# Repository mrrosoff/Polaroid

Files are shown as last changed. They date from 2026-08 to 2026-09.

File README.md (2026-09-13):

# Polaroid

A battery-powered digital Polaroid. A 4" six-color e-ink panel that lives on a fridge, cycles
through photos, and syncs new ones when you shake it. Runs about a month per charge. Built as a
wedding gift.

## How it works

The server pre-renders every photo into a raw framebuffer matching the panel's resolution and
palette exactly, so the device never decodes, dithers or resizes. It wakes, streams a file from
flash to the panel, and sleeps.

```
 photo.jpg ──▶ [ backend ]                      [ device ]
                 crop 400×600 full-bleed          wake (timer or shake)
                 Polaroid film curve              read index from RTC memory
                 Floyd-Steinberg → 6 inks         stream .bin from LittleFS → SPI
                 pack 4bpp → 120,000 B            deep sleep
                 store .bin + preview.png
```

The device always pulls, and the server never reaches back. That is what lets it sleep behind a NAT
on someone else's WiFi for months.

Every wake renders, and some also sync. A shake, a cold boot, or the daily interval coming due will
each do it. The manifest is newest-first, so index 0 is the newest photo. A shake, a cold boot, and
a sync that deleted photos all jump to index 0, and every other wake advances by one and wraps.

Two screens are not photos. Below 5% the panel stops refreshing and shows **CHARGE ME**, clearing
once above 25%, and the gap stops a cell on the threshold swapping every hour. An empty library
shows **ADD PHOTOS**, so a device that has never synced doesn't look broken. The battery card wins
when both apply.

Failure means "keep showing what's already there". A sync that fails falls through to a normal
render, so the panel never goes blank because the network was unhappy.

## Build and flash

```bash
pio run -t upload    # the shipping firmware
pio test -e native   # 39 tests, no hardware needed
```

There is one firmware environment. `logf()` writes to USB serial when a host is attached and
returns immediately when one is not, so bench and battery runs are the same binary.

Deep sleep drops USB, so a sleeping board can only be reflashed by holding BOOT through a reset, or
by catching the few seconds it is awake.

Copy `include/Secrets.h.example` to `Secrets.h` (gitignored) for the device credential and
WiFi networks. The strongest listed network in range wins, so both homes can be listed.

## Hardware

A **Seeed XIAO ESP32S3**, chosen because it charges the cell over the same USB-C you flash through,
has no always-on power LED, and is designed for a 14 µA deep sleep. Its 8 MB costs 50 photos
against a 16 MB board's 123, which is the trade.

The panel is a **Waveshare 4" E Ink Spectra 6 (E6)** with its HAT+ driver board, `EPD_4in0e`.
Native 400 × 600 portrait, 4 bpp, two pixels per byte, which works out to a fixed 120,000 bytes
per frame. Six inks, no grays and no blends. A full refresh takes 15–35 s, measured around 21 s on
this build.

| | black | white | yellow | red | blue | green |
| --- | --- | --- | --- | --- | --- | --- |
| nibble | `0x0` | `0x1` | `0x2` | `0x3` | `0x5` | `0x6` |

Also inside are an Adafruit #2011 2000 mAh cell and an Adafruit #2809 LIS3DH breakout. Orient the
LIS3DH so its X axis lies in the plane of the fridge door, because that is the axis the `Config.h`
thresholds are tuned against. The case is 71.6 × 118.8 × 22.7 mm, its footprint set by the driver
board.

### Wiring

The XIAO breaks out exactly eleven GPIO and this design needs exactly eleven. Every wake source
must be on GPIO0–21 (the RTC domain) and the battery divider must be on ADC1 (the ADC that still
answers while WiFi is up). `D6`/`D7` are GPIO43/44, outside both, so they take the two signals
needing neither.

| Panel | XIAO | GPIO | | LIS3DH | XIAO | GPIO |
| --- | --- | --- | --- | --- | --- | --- |
| `SCK` | D6 | 43 | | `SCL` | D3 | 4 |
| `MOSI` | D7 | 44 | | `SDA` | D2 | 3 |
| `CS` | D10 | 9 | | `INT1` | D1 | 2 |
| `DC` | D9 | 8 | | `3Vo` | 3V3 | |
| `RST` | D8 | 7 | | `GND` | GND | |
| `BUSY` | D5 | 6 | | | | |
| `PWR` | D4 | 5 | | | | |

The cell goes to `B+`/`B-` on the XIAO's underside, sensed through a 2 × 1 MΩ divider into `D0`
(GPIO1, ADC1_CH0). Tests assert no pin is used twice, that `INT1` is RTC-capable, and that battery
sense is on ADC1, so a mistake here fails on your laptop.

Two things will cost you the battery if you skip them. **Gate the panel through `D4`**, because the
E6 driver board's regulator idles in the hundreds of µA even after the panel sleeps, roughly halving
runtime. **Power the LIS3DH at `3Vo`**, bypassing the breakout's LDO and its 29 µA quiescent draw.

## Power

Measured at about 2.2 mA, which is roughly a month per charge.

Nothing the firmware *does* moves that number. Twenty-four refreshes a day, the syncs and the
filesystem together change the discharge rate by less than the measurement noise, so lengthening
`REFRESH_INTERVAL_SECONDS` buys nothing. What the firmware *leaves behind* was most of the drain.
The panel board stays powered while we sleep and pulls its inputs up to its own VCC, so holding the
six data and control lines at 0 V sank current through those pull-ups continuously. Leaving them
high-impedance instead cut about 1.9 mA.

The ~2 mA that remains is the driver board's own quiescent draw on a rail that never turns off.
Getting past it means hardware, namely a high-side P-MOSFET on its VCC rather than a GPIO, since the
board pulls ~45 mA during a refresh.

**Measure it with the on-flash log, never over USB.** The ADC divider sits on the battery terminal,
so a board on a charger reads the charger. Every wake appends `boot,rtc_ms,mv,wake,host` to
`/vlog.csv`. Plug in and shake to dump it, or send `c` to clear. Fit a slope through the `host=0`
rows ordered by `rtc_ms`, and compare slopes only within the same voltage window, since a LiPo's mV
per mAh changes across the curve.

## Protocol

Base URL `https://api.maxrosoff.com/polaroid`. Device requests carry a bearer token of the form
`<deviceId>.<secret>`, both in `Secrets.h`. The API stores only the secret's SHA-256 alongside the
id in the `website-devices` table. It is a static secret rather than a JWT because the device has no
clock worth trusting an `exp` against.

`GET /photos` returns `{ id, hash, uploadedAt, previewUrl }`, newest first and uncapped. The device
keeps the newest `MAX_PHOTOS` in that order and diffs against its local manifest for fetch, delete
and keep sets. Only fetch costs bandwidth.

`POST /photo` with `{ "id": ... }` returns exactly 120,000 bytes. It **must** send
`Accept: application/octet-stream`, or API Gateway returns 160,000 base64 characters instead. It
honours the Lambda's `isBase64Encoded` only when Accept matches the API's `binaryMediaTypes`.
Success is the file being exactly 120,000 bytes once closed, so a truncated body, a 404 and a
dropped connection all land as a short file and retry next sync.

`POST /upload` and `POST /remove` sit behind the site's passkey auth, and the device never calls
them.

There is no database for photos. The list is a `ListObjectsV2` whose Key, ETag and LastModified are
exactly the id, hash and timestamp a table would hold.

## Where the code lives

This repo is the device. The service lives in
[Personal-Website](https://github.com/mrrosoff/Personal-Website), which holds the image pipeline
and four Lambda handlers under `api/endpoints/polaroid/`, plus the upload page at
`maxrosoff.com/polaroid`.

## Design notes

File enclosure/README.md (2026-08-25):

# Enclosure

Two printed parts — front bezel and rear tray — held together by four M2 self-tapping screws that
enter horizontally through the tray's side walls into flanges on the bezel.

**71.6 × 118.8 × 22.7 mm.**

```bash
./render.sh          # regenerates every STL and preview from the .scad
```

The checked-in `stl/` and `preview/` files are outputs. Run `render.sh` after any change.

## Before you print

**Measure `board_t`.** 7.0 mm, calipered on the real board with the Pi headers removed. It sets the
total thickness directly, and the vendor doesn't give it.

**Check which edge the FPC leaves on.** `fpc_fold_gap` puts a 2.5 mm gap at the case's bottom edge
for the ribbon to fold into. On the wrong edge, assembly crushes it.

**Print the bezel in a dark colour.** E-ink white is bone, around 78% reflectance. A white bezel
around it reads as one big dingy slab and the Polaroid shape drawn on the panel disappears. Dark
grey, black, or a wood-fill makes the white pop.

## Notes

**Screws, not clips.** This is the one enclosure here that gets deliberately shaken.

**Screws live in the top and bottom rims, not the side margins.** That's what let the flanges get
longer *and* the side bezels get thinner — otherwise those trade directly against each other, since
a flange in the side margin forces that margin to be `flange_inset + flange_w + clearance` wide.
Side bezel is 1.5 mm of plastic beside the board — the wall, and nothing else — and 8.1 mm beside
the visible image. The rims are 7.35 mm, which is the screw head clearing the corner radius plus the
boss behind it, and nothing more. The boss is 4.5 mm around a 2.0 mm pilot, so its wall is 1.25 mm —
thin, deliberately, because the boss diameter is the rim's entire cost. If a flange splits on first
assembly, `side_boss_od` is the number that did it.

**One magnet, dead centre.** Anywhere else and the case rotates until its centre of mass hangs under
the magnet. The pocket recesses it flush so the case sits flat instead of pivoting on a bump.
The pocket swallows it with 0.8 mm to spare, so the hold comes through a thin skin rather than the
magnet's own face — a magnet standing even 0.2 mm proud is what the case then rocks on. Its ceiling
is a 29 mm circular bridge; if your printer sags there, pause at that layer and drop the magnet in —
it's adhesive-backed.

**The floor is 1.5 mm, and the magnet sits in a boss.** The floor used to be 5.6 mm everywhere so
that a 3 mm disc in the middle intruded on nothing — 4 mm of case thickness bought for one circle.
Now the floor is the wall thickness and the 5 mm the magnet needs is paid for over a 34 mm boss
standing proud on the inside. The cost is that the floor is no longer flat, so the component
placements are hoisted to the top level and asserted clear of the boss.

**There is no chin.** There was 10 mm of one, on the theory that the parts had run out of floor under
a board that spans the entire pocket. Laid out against the real footprints they had not — battery
along the top wall, MCU and accelerometer along the bottom, 30 mm of nothing between them. The
placement assertions are the claim that this is true, and they pass at `chin = 0`.

**The assertions are load-bearing.** They check that the screw flanges exist where the screws
arrive, that the head's counterbore lands on flat wall rather than the corner radius, that neither
reaches the display board, and that no component on the tray floor lands on the magnet boss. One caught a 2.5 mm overhang while this file was being written;
that class of error is invisible until something is printed and assembled.

**`render.sh` also intersects the two parts.** The assertions compare numbers to numbers and
structurally cannot see two solids sharing space. That is what let the bezel's square flange corners
sit 0.67 mm inside the tray's rounded interior corners, down all 12 mm of flange — which held the
bezel proud at four points and bowed its long sides when the screws pulled the ends down. The
intersection must come out empty; `fit_check.scad` is the model, and the build fails on anything
else.

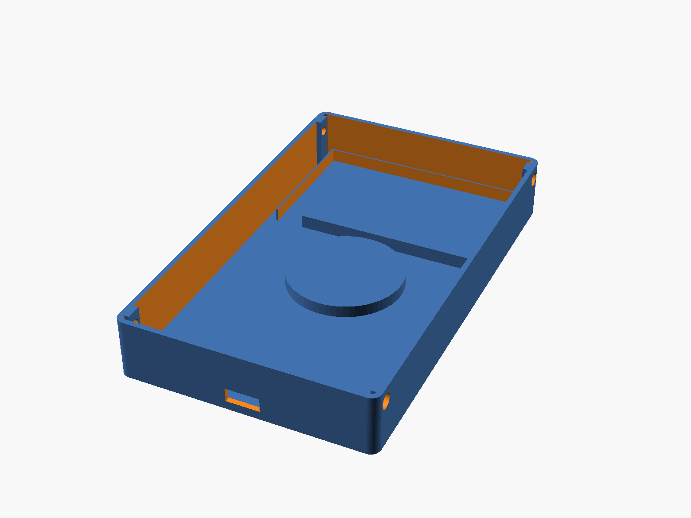
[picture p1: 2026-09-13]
enclosure/preview/03_tray_interior.png

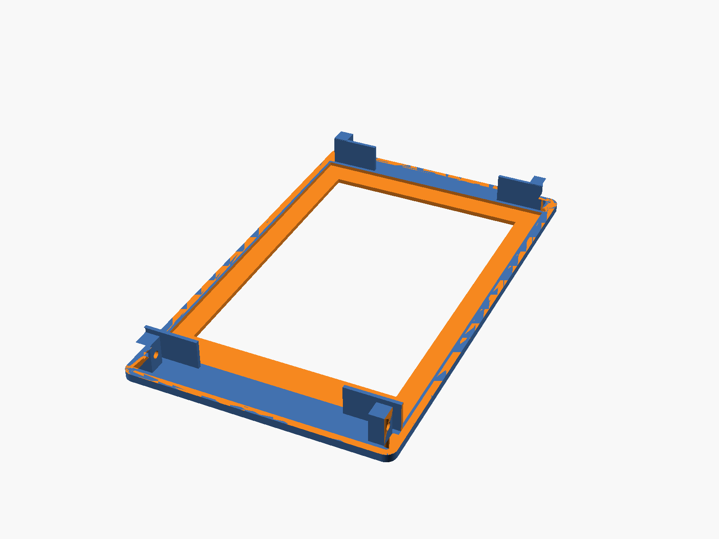
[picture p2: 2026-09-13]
enclosure/preview/02_bezel_iso.png

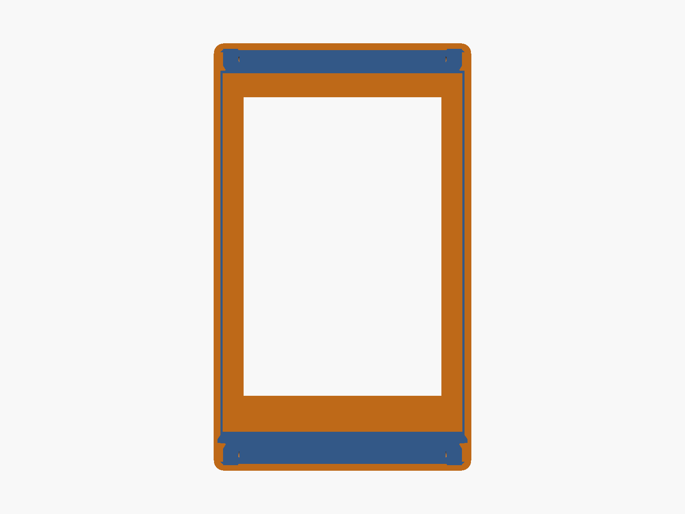
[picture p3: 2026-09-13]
enclosure/preview/01_bezel_front.png

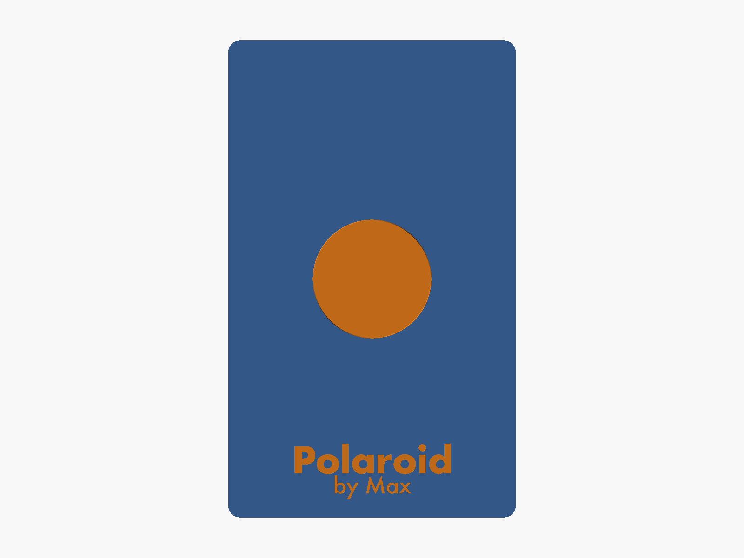
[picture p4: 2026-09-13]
enclosure/preview/04_tray_back.png

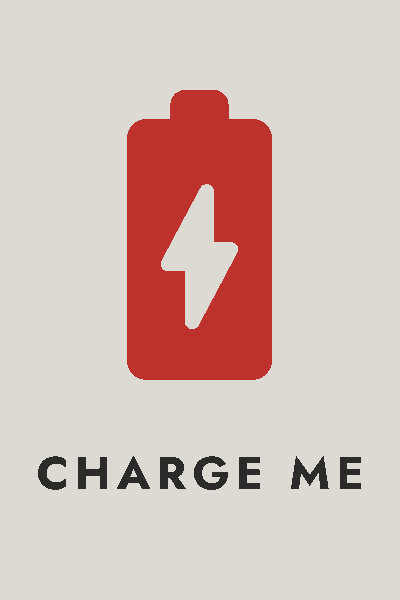
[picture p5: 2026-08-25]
tools/charge_me_preview.png

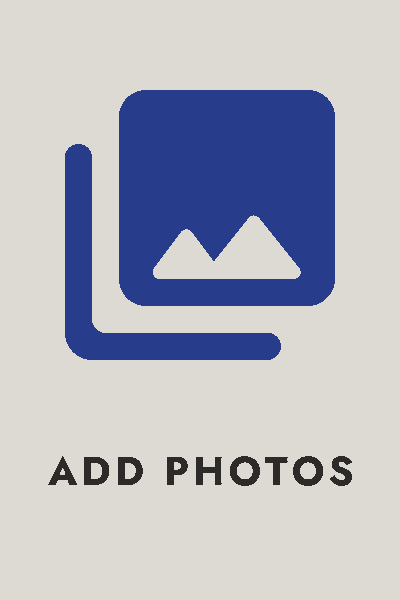
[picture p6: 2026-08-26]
tools/add_photos_preview.png

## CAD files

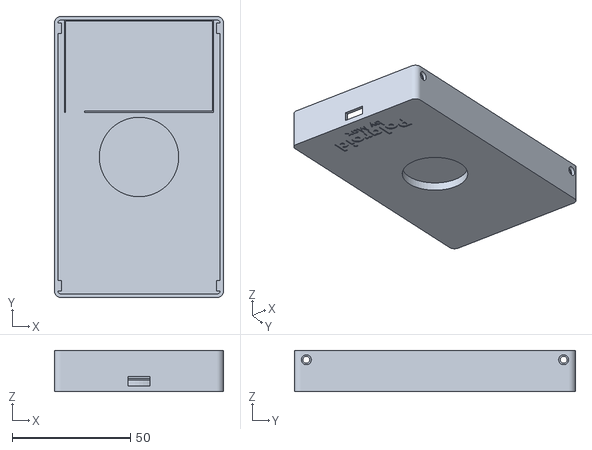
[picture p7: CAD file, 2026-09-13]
enclosure/stl/rear_tray.stl
71.6 x 118.8 x 17.5

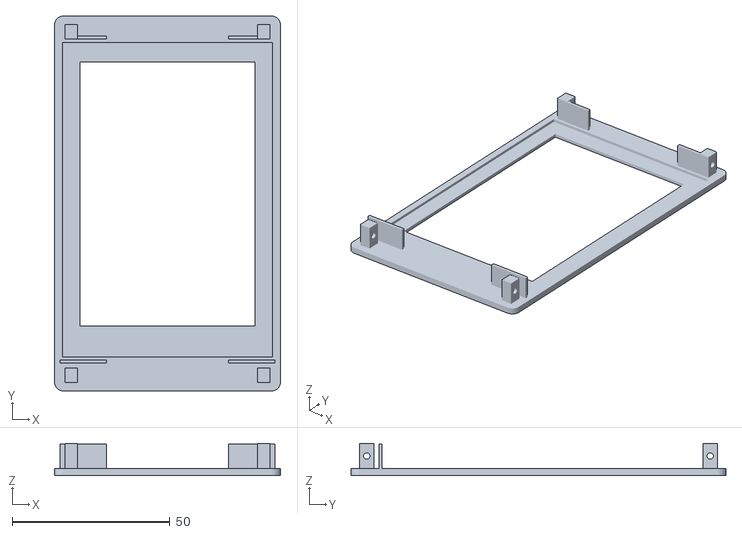
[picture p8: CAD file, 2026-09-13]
enclosure/stl/front_bezel.stl
71.6 x 118.8 x 10.2

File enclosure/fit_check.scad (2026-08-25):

// Interference check: the two parts, assembled, must not share any volume.
// Renders empty when they don't. render.sh fails on anything else.
//
// This is the one class of error the assertions in polaroid_enclosure.scad
// cannot see — they check numbers against each other, not solids against
// solids. It caught square flange corners buried 0.67mm in the tray's rounded
// interior corners, which held the bezel proud and bowed its long sides.
use <polaroid_enclosure.scad>

// The parts are drawn in one XY frame and mate by flipping Z about the plane
// where the bezel's back face meets the tray's rim.
mate_z = total_thickness_mm();

intersection() {
    translate([0, 0, mate_z]) mirror([0, 0, 1]) front_bezel();
    rear_tray();
}

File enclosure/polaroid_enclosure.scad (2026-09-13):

// Polaroid enclosure — 2-part (front bezel + rear tray), screwed together.
//
// The panel is natively 400x600 portrait, so case-X is width and case-Y is
// height, running along the panel's long 101mm edge.
//
// Hardware (vendor spec, waveshare.com/wiki/4inch_e-Paper_HAT+_(E)_Manual):
//   - Driver board (HAT+):  101.0 x 68.0mm      <- sets the case footprint
//   - Raw panel glass:       99.0 x 66.0 x 0.85mm
//   - Active area:           84.6 x 56.40mm
//   - MCU: Seeed XIAO ESP32S3, 21 x 17.5mm
//   - Battery: Adafruit #2011 LiPo, 60 x 36 x 7mm
//   - Accelerometer: Adafruit LIS3DH breakout, 25 x 19mm
//   - Magnet: one 29mm dia x 3mm neodymium disc, adhesive-backed
//
// The photo runs full-bleed across all 400x600 and nothing hides behind the
// bezel: a chin kept for looks would have to cover a quarter of a $45 panel.
//
// PRINT IT IN A DARK COLOUR. E-ink white is bone (~78% reflectance); a white
// bezel reads as one dingy slab and the Polaroid shape vanishes.
//
// Screws rather than clips: this is the one enclosure in the house that gets
// deliberately shaken, and snap-fit works loose.
//
// Render one part at a time:
//   openscad -D part=\"bezel\" -o stl/front_bezel.stl polaroid_enclosure.scad
//   openscad -D part=\"tray\"  -o stl/rear_tray.stl   polaroid_enclosure.scad
part = "both"; // "bezel" | "tray" | "both" (both = preview only, side by side)

$fn = 64;

// ---- General ----
wall      = 1.5;   // perimeter wall thickness
clearance = 0.3;   // general fit clearance around boards
// The corner and the screw head compete for the same end of the case: the head
// must seat on flat wall outboard of the radius, so every 0.1 of radius pushes
// the screw 0.1 further in and costs 0.1 more rim behind it.
corner_r  = 2.8;

// ---- Side-entry screws ----
// SCREWS LIVE IN THE TOP AND BOTTOM RIMS, NOT THE SIDE MARGINS. A flange in a
// side margin forces that margin to flange_inset + flange_w + clearance, so
// every millimetre of thread engagement costs a millimetre of bezel on both
// sides. At a Y above or below the board there is nothing to collide with, so
// the side margin drops to a bare wall and the flange can be as deep as the
// joint needs.
//
// 4.5 around a 2.0mm pilot leaves a 1.25mm wall, the section that split on the
// Forager print. It is back because the boss diameter is the rim's whole cost,
// and because this flange is 12mm deep into a screw pad rather than a stub in
// open air. If a flange splits on first assembly, this is the number that did
// it.
side_boss_od      = 4.5;
side_pilot_d      = 2.0;   // M2 self-tapping into plastic
side_clear_d      = 2.9;   // shaft passes freely through the tray wall
// Flat-top heads sink flush in a counterbore outside the tray. A 1.6mm head
// into a 1.5mm wall leaves nothing to pull against, so the wall is thickened
// locally with a pad on the INSIDE that the bezel's flange butts against.
head_clear_d      = 4.2;   // 3.8mm M2 pan/cheese head plus fit
head_recess_t     = 1.6;   // full head height — the head disappears
screw_pad_t       = 1.5;
flange_w          = 4.0;   // thread engagement depth
// How far the flange reaches into the tray cavity. It has to stop above the
// battery bay's retaining wall, which it overlaps in plan: 12.0 was fine under
// a 19mm cavity and drove the flange straight through the bay at 12.5.
side_flange_depth = 8.0;
// Clear of the screw pad's inner face, not of the wall's.
flange_inset      = wall + screw_pad_t + clearance;   // 3.3

assert(head_recess_t <= wall + screw_pad_t - 1.2,
       "counterbore leaves under 1.2mm of wall — the head will pull through");

// ---- Display assembly ----
// The BOARD, not the glass, sets the footprint: it's 2mm bigger in both axes.
board_w = 68.0;
board_h = 101.0;
// Measured with calipers, headers removed — but see measured_stack_t, which
// says this reads about 5mm high. Re-measure before trusting it.
board_t = 7.0;

glass_w = 66.0;
glass_h = 99.0;
glass_t = 0.85;    // the glass is genuinely this thin. Handle it accordingly.

active_w = 56.40;
active_h = 84.60;

// ASSUMPTION: the active area is centred on the glass and the glass on the
// board. Vendor drawings give no offsets. Shift with active_offset_* rather
// than moving the pocket. Positive Y moves the window up; the value below is
// what the second printed bezel measured short.
active_offset_x = 0;
active_offset_y = 1.7;

// The bezel laps 0.5mm over the active area on every side. Sizing the window
// to exactly active_w/h would expose the glass's inactive margin as a visible
// grey band whenever the panel is showing white paper.
win_overlap = 0.5;
win_w = active_w - 2 * win_overlap;
win_h = active_h - 2 * win_overlap;

// ASSUMPTION: the FPC exits the glass on the case's BOTTOM edge and folds back
// to the board's connector. This is the gap it folds into. Verify which edge
// yours is on before printing — on the wrong edge it crushes the ribbon.
fpc_fold_gap = 2.5;

// ---- MCU: Seeed XIAO ESP32S3 ----
mcu_w = 21.0;
mcu_l = 17.5;
mcu_component_h = 4.0;  // USB-C shell is the tall part

// ---- Battery: Adafruit #2011, 2000mAh ----
batt_w = 60.0;
batt_h = 36.0;
batt_t = 7.0;
batt_puff_clearance = 2.0;  // Same cell as Forager, same allowance: its
                            // 2.0 came off a real print, this was a guess.

// ---- Accelerometer: Adafruit LIS3DH breakout ----
accel_w = 25.0;
accel_l = 19.0;
accel_h = 3.0;

// ---- Magnet ----
// Dead centre is the only sane place for a single disc: anywhere else and the
// case rotates until its centre of mass swings under the magnet. The pocket
// exists so the magnet sits below the back face — standing proud, it is the
// one bump the case rocks on and it never sits flat against the door.
magnet_d = 29.0;
magnet_t = 3.0;
magnet_pocket_d = magnet_d + 0.6;
magnet_pocket_depth = magnet_t + 0.8;
magnet_back_t = 1.2;    // material left behind the magnet. 0.8 was thin
                        // enough to feel like a membrane; this still holds

// The pocket lives in a boss standing proud of the floor on the INSIDE, so its
// depth is paid for over 34mm of circle rather than by thickening the whole
// back — worth 4mm of case. The cost is that the floor is not flat, and the
// component placements below are asserted clear of the boss.
tray_floor_t = wall;   // 1.5
magnet_boss_h = 3.5;
magnet_boss_d = magnet_pocket_d + 4.0;   // 2mm ring around the pocket

assert(tray_floor_t + magnet_boss_h >= magnet_pocket_depth + magnet_back_t,
       "magnet pocket breaks through the boss into the cavity");

// ---- USB-C access ----
usbc_slot_w = 9.5;
usbc_slot_h = 4.0;

// ---- Derived footprint ----
pocket_w = board_w + 2 * clearance;
pocket_h = board_h + 2 * clearance + fpc_fold_gap;

// The pocket IS the tray's interior, so the board is located in X by the wall
// itself to its 0.3mm clearance — tighter than locator brackets managed.
pocket_x_inset = wall;   // 1.5

// Rims above and below the board, sized to just contain a screw boss clear of
// the rounded corner. This is the one place the case is bigger than the board
// needs, and it buys the thin side bezels.
//
// The head, not the shaft, sets the screw centre: the counterbore has to land
// on flat wall. The 0.1 is not decoration — at exact equality the assertion
// below fails on floating point.
side_y_lo = corner_r + head_clear_d / 2 + 0.1;   // 5.0
// Derived from the screw rather than the screw from the rim, which is worth
// 2mm of height and cannot put the boss over the board.
rim = side_y_lo + side_boss_od / 2 + 0.1;  // 8.25

// The placement assertions below are the test of whether the parts need extra
// floor, and they pass at zero. Kept as a knob because a part that grows is
// the reason it would come back.
chin = 0;

outer_w = pocket_w + 2 * pocket_x_inset;   // ~73.6
outer_h = pocket_h + 2 * rim + chin;

bezel_front_t = 2.2;
glass_pocket_w = glass_w + 2 * clearance;
glass_pocket_h = glass_h + 2 * clearance;
glass_pocket_d = 1.0;   // shallow recess that locates the 0.85mm glass

// Locator bars on the bezel's back face, so a device shaken on purpose does
// not rattle its panel loose. Only Y needs holding — the tray wall takes X.
// Bars at the ends rather than one rib per edge: the FPC leaves the middle of
// the bottom edge and a continuous rib would pinch it.
rib_t = 1.0;
rib_arm = 15.0;
rib_h = glass_t + board_t;

// The bezel is a plate, not a pocket, so the whole display stack lives in the
// tray's cavity on top of the battery layer. MCU, accelerometer and battery
// sit side by side in plan, hence the max; the board spans the full footprint
// above them, hence the sum.
component_h = max(batt_t + batt_puff_clearance, mcu_component_h, accel_h);

measured_stack_t = 15.5;   // second build, dressed flat. Was 19.0.
tray_interior_depth = measured_stack_t + 0.5;
tray_wall_h = tray_interior_depth + tray_floor_t;
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

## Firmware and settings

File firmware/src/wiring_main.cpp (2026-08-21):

// Wiring bring-up only. Built by `pio run -e wiring-test`, which swaps this in
// for main.cpp — no filesystem, no network. It drives the real Panel and the
// real I2C bus, so a pass exercises the same init sequence the firmware ships.
//
// What the pattern tells you:
//   red band along the top   - row order and orientation are right way up
//   six bars, left to right  - black white yellow red blue green
//   bars evenly wide, sharp  - 4bpp packing and the nibble map are correct
//   a bar in the wrong hue   - data line swapped, or 0x4 crept into the map
//   sheared or smeared bars  - SPI clock too fast, or CS released mid-transfer

#include <Arduino.h>
#include <Wire.h>

#include <cstdint>

#include "Battery.h"
#include "Config.h"
#include "Overlay.h"
#include "Panel.h"
#include <span>

namespace {

constexpr std::uint16_t BAR_COUNT = 6;
constexpr config::Ink BARS[BAR_COUNT] = {
    config::INK_BLACK, config::INK_WHITE, config::INK_YELLOW,
    config::INK_RED,   config::INK_BLUE,  config::INK_GREEN,
};

constexpr std::uint16_t TOP_BAND_ROWS = 20;

constexpr std::uint8_t LIS3DH_WHO_AM_I = 0x0F;
constexpr std::uint8_t LIS3DH_WHO_AM_I_EXPECTED = 0x33;

void testPattern(std::uint16_t row, std::span<std::uint8_t> rowBytes) {
    if (row < TOP_BAND_ROWS) {
        for (std::uint16_t x = 0; x < config::PANEL_WIDTH; ++x) {
            polaroid::setPixel(rowBytes, x, config::INK_RED);
        }
        return;
    }

    for (std::uint16_t x = 0; x < config::PANEL_WIDTH; ++x) {
        const std::uint16_t bar =
            static_cast<std::uint16_t>(x * BAR_COUNT / config::PANEL_WIDTH);
        polaroid::setPixel(rowBytes, x, BARS[bar]);
    }
}

// Is BUSY driven? Pull it both ways and see if it follows. A line the panel is
// holding ignores the internal pull; a disconnected or unpowered one tracks it.
bool busyIsDriven() {
    pinMode(config::PIN_EPD_BUSY, INPUT_PULLUP);
    delay(10);
    const int pulledUp = digitalRead(config::PIN_EPD_BUSY);

    pinMode(config::PIN_EPD_BUSY, INPUT_PULLDOWN);
    delay(10);
    const int pulledDown = digitalRead(config::PIN_EPD_BUSY);

    pinMode(config::PIN_EPD_BUSY, INPUT);
    Serial.printf("      pullup=%d pulldown=%d\n", pulledUp, pulledDown);
    return !(pulledUp == 1 && pulledDown == 0);
}

// Panel::begin() drives the gate HIGH unconditionally. If the part is
// P-channel that turns the rail OFF, which from the BUSY side looks identical
// to a missing wire. Try it both ways before blaming the solder.
void probePanelRail() {
    pinMode(config::PIN_EPD_PWR, OUTPUT);

    Serial.printf("      BUSY is GPIO%d, PWR gate is GPIO%d\n", config::PIN_EPD_BUSY,
                  config::PIN_EPD_PWR);

    digitalWrite(config::PIN_EPD_PWR, HIGH);
    delay(100);
    Serial.println("      gate HIGH:");
    const bool drivenHigh = busyIsDriven();

    digitalWrite(config::PIN_EPD_PWR, LOW);
    delay(100);
    Serial.println("      gate LOW:");
    const bool drivenLow = busyIsDriven();

    // Leave the rail in whichever state produced a live panel.
    digitalWrite(config::PIN_EPD_PWR, (drivenLow && !drivenHigh) ? LOW : HIGH);
    delay(100);

    if (drivenHigh) {
        Serial.println("ok    panel drives BUSY with the gate HIGH, as the firmware assumes");
    } else if (drivenLow) {
        Serial.println("FAIL  BUSY is only driven with the gate LOW - the gate is inverted.");
        Serial.println("      PIN_EPD_PWR needs active-low polarity in Panel::begin.");
    } else {
        Serial.println("FAIL  BUSY floats either way - not landed, or no power at the panel.");
    }
}

// Check the lines before handing them to Wire. A bus with no pull-ups, or one
// a device is holding down, makes endTransmission() block rather than NACK —
// which looks like a hang, not a missing part.
bool i2cLinesIdle() {
    pinMode(config::PIN_I2C_SDA, INPUT_PULLUP);
    pinMode(config::PIN_I2C_SCL, INPUT_PULLUP);
    delay(10);
    const int sdaPulled = digitalRead(config::PIN_I2C_SDA);
    const int sclPulled = digitalRead(config::PIN_I2C_SCL);

    // With the internal pulls off, only external resistors can hold these high.
    // The internal ones are ~45k and read high either way, so they prove
    // nothing about whether the breakout is actually on the bus.
    pinMode(config::PIN_I2C_SDA, INPUT);
    pinMode(config::PIN_I2C_SCL, INPUT);
    delay(10);
    const int sdaBare = digitalRead(config::PIN_I2C_SDA);
    const int sclBare = digitalRead(config::PIN_I2C_SCL);

    Serial.printf("      SDA=GPIO%d pulled=%d bare=%d\n", config::PIN_I2C_SDA, sdaPulled,
                  sdaBare);
    Serial.printf("      SCL=GPIO%d pulled=%d bare=%d\n", config::PIN_I2C_SCL, sclPulled,
                  sclBare);

    if (sdaPulled == 0 || sclPulled == 0) {
        Serial.println("FAIL  a line is stuck low - shorted, or a device is holding the bus");
        return false;
    }
    if (sdaBare == 0 && sclBare == 0) {
        Serial.println("FAIL  no external pull-ups - the LIS3DH breakout is not on this bus");
        Serial.println("      (its 10k pull-ups would hold both lines high on their own)");
        return false;
    }

    Serial.println("ok    external pull-ups present, bus is idle");
    return true;
}

// The divider is 2 x 1 MΩ off B+, so the ADC sees half the cell. An
// unconnected D0 floats and reads near zero, which is the failure this
// distinguishes from a genuinely flat battery.
void probeBattery() {
    const polaroid::BatteryReading reading = polaroid::readBattery();
    const float atPin = reading.volts / config::VBAT_DIVIDER_RATIO;

    Serial.printf("      VBAT=%.3f V (%.3f V at GPIO%d), %u%%%s%s\n", reading.volts, atPin,
                  config::PIN_VBAT_SENSE, reading.percent, reading.low ? " LOW" : "",
                  reading.critical ? " CRITICAL" : "");

    if (reading.volts < 1.0f) {
        Serial.println("FAIL  reads near zero - D0 is floating or the divider is not landed");
    } else if (reading.volts > 4.4f) {
        Serial.println("FAIL  reads above a full cell - is D0 on B+ directly, without R1?");
    } else {
        Serial.println("ok    in range; meter B+ and correct VBAT_ADC_CALIBRATION if it differs");
    }
}

void probeAccelerometer() {
    if (!i2cLinesIdle()) {
        return;
    }

    Wire.begin(config::PIN_I2C_SDA, config::PIN_I2C_SCL);
    // Without this a stalled bus blocks for a second per address, and a full
    // scan never returns.
    Wire.setTimeOut(20);
    delay(10);

    // Only the two addresses the LIS3DH can take. A full 112-address sweep
    // cannot finish if the peripheral stalls, and the print before each attempt
    // is what shows which address it wedged on.
    int found = 0;
    for (std::uint8_t addr : {std::uint8_t{0x18}, std::uint8_t{0x19}}) {
        Serial.printf("      trying 0x%02X\n", addr);
        Wire.beginTransmission(addr);
        const std::uint8_t result = Wire.endTransmission();
        Serial.printf("      0x%02X -> %d\n", addr, result);
        if (result == 0) {
            ++found;
        }
    }
    if (found == 0) {
        // Code 5 is a timeout, not a NACK. A missing chip NACKs (2); a timeout
        // with healthy pull-ups means the clock and data are not reaching it —
        // which is what SDA and SCL swapped looks like from here.
        Serial.println("      no answer; retrying with SDA and SCL swapped");
        Wire.end();
        delay(10);
        Wire.begin(config::PIN_I2C_SCL, config::PIN_I2C_SDA);
        Wire.setTimeOut(20);
        delay(10);

        for (std::uint8_t addr : {std::uint8_t{0x18}, std::uint8_t{0x19}}) {
            Wire.beginTransmission(addr);
            const std::uint8_t result = Wire.endTransmission();
            Serial.printf("      swapped 0x%02X -> %d\n", addr, result);
            if (result == 0) {
                Serial.println("FAIL  the accelerometer answers with SDA and SCL SWAPPED.");
                Serial.printf("      PIN_I2C_SDA and PIN_I2C_SCL are reversed: SDA is on "
                              "GPIO%d, SCL on GPIO%d\n",
                              config::PIN_I2C_SCL, config::PIN_I2C_SDA);
                return;
            }
        }
        Serial.println("FAIL  no answer either way - check VIN, GND and both signal wires");
        return;
    }

    Wire.beginTransmission(config::ACCEL_I2C_ADDRESS);
    Wire.write(LIS3DH_WHO_AM_I);
    if (Wire.endTransmission(false) != 0) {
        Serial.printf("FAIL  no LIS3DH at 0x%02X (SDO/SA0 picks 0x18 vs 0x19)\n",
                      config::ACCEL_I2C_ADDRESS);
        return;
    }
    Wire.requestFrom(static_cast<std::uint8_t>(config::ACCEL_I2C_ADDRESS),
                     static_cast<std::uint8_t>(1));
    const std::uint8_t who = Wire.available() ? Wire.read() : 0;

    if (who == LIS3DH_WHO_AM_I_EXPECTED) {
        Serial.printf("ok    LIS3DH at 0x%02X, WHO_AM_I=0x%02X\n", config::ACCEL_I2C_ADDRESS,
                      who);
    } else {
        Serial.printf("FAIL  WHO_AM_I=0x%02X, expected 0x%02X\n", who,
                      LIS3DH_WHO_AM_I_EXPECTED);
    }
}

}  // namespace

void setup() {
    Serial.begin(115200);
    // USB CDC enumerates after boot; without this the first prints are lost.
    delay(2000);
    Serial.println();
    Serial.println("polaroid wiring test");

    Serial.println("--- battery ---");
    probeBattery();

    Serial.println("--- accelerometer ---");
    probeAccelerometer();

    Serial.println("--- panel rail ---");
    probePanelRail();

    Serial.println("--- panel ---");
    polaroid::Panel panel;
    const std::uint32_t started = millis();
    const bool up = panel.begin();
    const std::uint32_t elapsed = millis() - started;

    if (!up) {
        // begin() waits for idle twice, once after reset and once after the
        // init sequence, each with the same timeout. Roughly one timeout means
        // the panel never came out of reset; roughly two means it accepted the
        // reset and then wedged on the init sequence.
        Serial.printf("FAIL  panel.begin() after %lu ms\n", static_cast<unsigned long>(elapsed));
        if (elapsed < config::EPD_BUSY_TIMEOUT_MS + 5000) {
            Serial.println("      timed out on the FIRST wait - panel never released BUSY");
            Serial.println("      after reset. Check RST and the panel rail.");
        } else {
            Serial.println("      reset was accepted; it wedged on the init sequence.");
            Serial.println("      Check MOSI, SCK, CS and DC.");
        }
        return;
    }

    Serial.printf("ok    panel init done after %lu ms, streaming pattern\n",
                  static_cast<unsigned long>(elapsed));

    const std::uint32_t refreshStart = millis();
    const bool sent = panel.displayGenerated(testPattern);
    const std::uint32_t refreshMs = millis() - refreshStart;

    if (!sent) {
        Serial.printf("FAIL  displayGenerated() after %lu ms\n",
                      static_cast<unsigned long>(refreshMs));
        return;
    }

    // A real refresh holds BUSY low for 15-35 s. Returning sooner means every
    // waitUntilIdle() passed on a line that was never asserted - the panel was
    // not listening, and the "success" is meaningless.
    if (refreshMs < 10000) {
        Serial.printf("FAIL  refresh returned in %lu ms; a real one takes 15-35 s.\n",
                      static_cast<unsigned long>(refreshMs));
        Serial.println("      BUSY never asserted, so the panel ignored the whole sequence.");
        return;
    }

    Serial.printf("ok    refresh took %lu ms; pattern is on the panel\n",
                  static_cast<unsigned long>(refreshMs));
}

void loop() {}

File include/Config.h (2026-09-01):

#pragma once

#include <array>
#include <cstdint>

/*
 * Every tunable in the firmware lives here. If you are calibrating on the real
 * fridge, everything you need is in the Motion section.
 */

namespace config {

// ---------------------------------------------------------------- panel

// Waveshare 4" E Ink Spectra 6 (E6), driver EPD_4in0e. Native portrait.
constexpr uint16_t PANEL_WIDTH = 400;
constexpr uint16_t PANEL_HEIGHT = 600;
constexpr uint32_t PANEL_ROW_BYTES = PANEL_WIDTH / 2;             // 4bpp, two pixels per byte
constexpr uint32_t PANEL_BYTES = PANEL_ROW_BYTES * PANEL_HEIGHT;  // 120,000

// The six inks, as the controller numbers them. There is nothing in between.
enum Ink : uint8_t {
    INK_BLACK = 0x0,
    INK_WHITE = 0x1,
    INK_YELLOW = 0x2,
    INK_RED = 0x3,
    INK_BLUE = 0x5,
    INK_GREEN = 0x6,
};

/*
 * Hold CS low across the whole 120 KB data phase instead of toggling it per byte
 * the way Waveshare's reference driver does. Same wire protocol, ~3x faster, and
 * at 45 mA the difference is worth real days of runtime. Set to 0 if a panel
 * turns out to be fussy about it.
 */
#define EPD_BULK_TRANSFER 1

constexpr uint32_t EPD_SPI_HZ = 20'000'000;

/*
 * Panel pulls BUSY low while refreshing. 35 s is the far end of the datasheet's
 * range; past that we assume the panel is wedged and sleep anyway rather than
 * spin on the pin until the battery is gone.
 */
constexpr uint32_t EPD_BUSY_TIMEOUT_MS = 40'000;

// ---------------------------------------------------------------- pins

/*
 * Two constraints drive every assignment here:
 *   every wake source must be on GPIO0-21, the S3's RTC domain
 *   the battery divider must be on ADC1 (GPIO1-10), the ADC that still
 *   works while WiFi is up
 */

/*
 * Seeed XIAO ESP32S3. Exactly eleven GPIO broken out and this design needs
 * exactly eleven, so there is no slack — D6/D7 are GPIO43/44, which are
 * outside the RTC domain and have no ADC, so they get the two signals that
 * need neither.
 */
constexpr int PIN_EPD_SCK = 43;   // D6
constexpr int PIN_EPD_MOSI = 44;  // D7
constexpr int PIN_EPD_CS = 9;     // D10
constexpr int PIN_EPD_DC = 8;     // D9
constexpr int PIN_EPD_RST = 7;    // D8
constexpr int PIN_EPD_BUSY = 6;   // D5
constexpr int PIN_EPD_PWR = 5;    // D4

/*
 * POWER: every pin that reaches the panel driver board, gate included. All of
 * them are driven low and held through deep sleep -- see sleepUntilNextEvent,
 * which explains why the gate alone is not enough.
 *
 * SCK and MOSI are 43 and 44, outside the RTC range, so they hold only because
 * gpio_deep_sleep_hold_en() covers digital pads too.
 */
constexpr std::array<int, 7> EPD_PINS{PIN_EPD_SCK, PIN_EPD_MOSI, PIN_EPD_CS, PIN_EPD_DC,
                                      PIN_EPD_RST, PIN_EPD_BUSY, PIN_EPD_PWR};

constexpr int PIN_I2C_SCL = 4;     // D3
constexpr int PIN_I2C_SDA = 3;     // D2
constexpr int PIN_ACCEL_INT1 = 2;  // D1, RTC-capable

constexpr int PIN_VBAT_SENSE = 1;  // D0, ADC1_CH0

/*
 * POWER: the XIAO's own user LED, and nothing here drives it. It is ACTIVE
 * LOW, so a floating pad lights it, which is what a bare GPIO does through
 * deep sleep unless it is held. Driven high and held before sleeping.
 */
constexpr int PIN_STATUS_LED = 21;

/*
 * Nothing left over that floats. The XIAO's remaining pads are the USB
 * differential pair and the internal flash/PSRAM bus, which must not be
 * touched -- and PIN_STATUS_LED, which is handled explicitly on the sleep path
 * because it needs a driven level, not a pull. Kept so that path can iterate
 * this without a special case.
 */
constexpr std::array<int, 0> UNUSED_PINS{};

/*
 * POWER: PIN_EPD_PWR gates the panel driver board's rail. Worth about 30 µA,
 * a third of the sleep budget. See the README.
 */

// ---------------------------------------------------------------- timing

constexpr uint32_t REFRESH_INTERVAL_SECONDS = 60 * 60;  // hourly

/*
 * POWER: this is the dominant term in the whole budget, not sleep current.
 * Doubling it to two hours buys roughly 60 extra days. See the README.
 */

constexpr uint32_t SYNC_INTERVAL_SECONDS = 24 * 60 * 60;

/*
 * A failed sync retries sooner than a day, then backs off: 1h, 2h, 4h ... up
 * to the normal interval. Without this a router outage retries every hour, and
 * 24 connect timeouts a day costs more than the entire rest of the budget.
 */
constexpr uint32_t SYNC_RETRY_BASE_SECONDS = 60 * 60;

/*
 * Draw the offline icon once this many syncs in a row have failed. Three is
 * about seven hours of backoff, so a brief blip never shows.
 */
constexpr uint8_t OFFLINE_ICON_AFTER_FAILURES = 3;

// Caps the backoff shift so it can't overflow.
constexpr uint8_t MAX_SYNC_FAILURES = 8;
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

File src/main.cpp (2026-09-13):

#include <Arduino.h>
#include <driver/gpio.h>
#include <esp_private/esp_clk.h>
#include <esp_system.h>
#include <esp_timer.h>

#include <cstdarg>

#include <algorithm>
#include <array>
#include <cstdint>
#include <span>
#include <string_view>

#include "Config.h"
#include "Manifest.h"
#include "Overlay.h"
#include "Secrets.h"
#include "StatusCard.h"
#include "drivers/Battery.h"
#include "drivers/Motion.h"
#include "drivers/Panel.h"
#include "drivers/Storage.h"
#include "net/Net.h"
#include "system/Log.h"
#include "system/State.h"
#include "system/VoltageLog.h"

using namespace config;
using namespace polaroid;

namespace {

Storage storage;
Motion motion;
Manifest manifest;
BatteryReading battery;

bool showOfflineIcon = false;

bool overlayHook(std::uint16_t row, std::span<std::uint8_t> rowBytes) {
    return showOfflineIcon ? offlineOverlay(row, rowBytes) : false;
}

/*
 * Identifies a rendered image. The hash is the object's ETag, so it moves when
 * the picture behind an id is replaced, and two ids never collide on it.
 */
std::uint32_t panelKey(const PhotoEntry& photo, bool overlay) {
    std::uint32_t hash = 2166136261u;
    for (char c : photo.hashView()) {
        hash = (hash ^ static_cast<std::uint8_t>(c)) * 16777619u;
    }
    return hash ^ (overlay ? 0x9E3779B9u : 0u);
}

/*
 * Renders whatever is at rtcState().photoIndex. Every failure here is
 * non-fatal: e-ink holds its last image, so the worst case is that the couple
 * looks at yesterday's photo for another hour.
 */
void renderCurrentPhoto() {
    RtcState& state = rtcState();

    /*
     * An empty library has to say so. E-ink holds its last image, so returning
     * here would leave whatever was drawn last sitting on the panel, and a
     * frame with nothing in it would look exactly like a frame that had
     * stopped working.
     *
     * Drawn once. The state persists until a sync brings a photo back, and
     * repainting the identical card on every wake would spend the whole daily
     * budget on it.
     */
    if (manifest.photos.empty()) {
        /*
         * A frame that has never held a photo shows nothing at all. It is a
         * gift, and the first thing anyone sees should be clean paper rather
         * than an instruction. Once it has held one, empty means they were
         * deleted, and that is worth saying.
         */
        const std::uint8_t want = storage.hasEverHeldPhoto() ? PANEL_NO_PHOTOS_CARD : PANEL_BLANK;
        if (state.panelShows == want) {
            return;
        }
        Panel panel;
        if (!panel.begin()) {
            return;
        }
        logf("panel", "painting %s", want == PANEL_BLANK ? "blank paper" : "the no-photos card");
        const bool drawn = want == PANEL_BLANK ? panel.displaySolid(config::INK_WHITE)
                                               : panel.displayGenerated(card::noPhotosCardRow);
        if (drawn) {
            state.panelShows = want;
        }
        return;
    }
    storage.markPhotoHeld();

    if (state.photoIndex >= manifest.photos.size()) {
        state.photoIndex = 0;
    }

    /*
     * A refresh the viewer cannot see is still a refresh. With one photo in the
     * library the index stays at zero, so every timer wake would repaint the
     * identical image: 24 full 21-second refreshes a day, flashing the panel
     * for nothing. Skip when what we would draw is already up.
     */
    const std::uint32_t key = panelKey(manifest.photos[state.photoIndex], showOfflineIcon);
    if (state.panelShows == PANEL_PHOTO && state.panelPhotoKey == key) {
        logf("panel", "photo %u of %u already shown, not repainting",
             static_cast<unsigned>(state.photoIndex + 1),
             static_cast<unsigned>(manifest.photos.size()));
        return;
    }
    logf("panel", "painting photo %u of %u%s", static_cast<unsigned>(state.photoIndex + 1),
         static_cast<unsigned>(manifest.photos.size()), showOfflineIcon ? " (offline)" : "");

    std::array<char, 48> path{};
    storage.photoPath(manifest.photos[state.photoIndex].idView(), path);

    /*
     * Scoped so the destructor cuts the panel rail on every path out of here,
     * including the early return above and anything that throws later.
     */
    Panel panel;
    if (!panel.begin()) {
        return;
    }
    if (panel.displayFile(storage.fs(), path.data(), showOfflineIcon ? overlayHook : nullptr)) {
        state.panelShows = PANEL_PHOTO;
        state.panelPhotoKey = key;
    }
}

/*
 * A wake either syncs or it does not. Motion always syncs -- INT1 has one
 * source and there is no second gesture to tell apart -- a cold boot syncs
 * because it has nothing to show and a zeroed clock, and the timer syncs once
 * its interval is up.
 */
[[nodiscard]] bool shouldSync(WakeReason reason) {
    if (reason == WakeReason::Motion || reason == WakeReason::ColdBoot) {
        return true;
    }
    return rtcState().secondsSinceSync >= syncInterval(rtcState().syncFailures);
}

/*
 * Debounce across deep sleep: hands bounce, and one shake otherwise reads as
 * four, each costing a sync.
 *
 * The clock must be the RTC's. esp_timer_get_time() counts from
 * esp_timer_init(), and a deep-sleep wake is an application startup, so it
 * restarts near zero every wake -- against which every shake looked like a
 * bounce and was discarded.
 *
 * esp_clk_rtc_time() lives behind esp_private/, so a framework bump can move
 * it. If it does, the replacement has to keep counting through deep sleep;
 * anything measuring uptime brings the bug straight back.
 */
bool motionTooSoon() {
    RtcState& state = rtcState();
    const std::uint64_t nowMs = esp_clk_rtc_time() / 1000ULL;

    /*
     * Zero is "no motion wake recorded yet" and must not read as "just now".
     * The old guard used bootCount > 1 for that, which does not cover the
     * first motion wake after a cold boot, where the stored value is still
     * zero.
     */
    if (state.lastMotionMs != 0 && nowMs - state.lastMotionMs < MOTION_DEBOUNCE_MS) {
        return true;
    }
    state.lastMotionMs = nowMs;
    return false;
}
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

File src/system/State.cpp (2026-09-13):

#include "State.h"

#include <WiFi.h>
#include <driver/gpio.h>
#include <esp_sleep.h>
#include <esp_wifi.h>

using namespace config;

namespace polaroid {

namespace {

RTC_DATA_ATTR RtcState state;

uint32_t computeChecksum(const RtcState& s) {
    /*
     * Everything but the checksum field itself. RTC memory survives deep sleep
     * but not a brownout, and a garbage photoIndex is how you end up showing
     * nothing at all.
     */
    const uint8_t* bytes = reinterpret_cast<const uint8_t*>(&s);
    size_t length = offsetof(RtcState, checksum);
    uint32_t hash = 2166136261u;
    for (size_t i = 0; i < length; i++) {
        hash = (hash ^ bytes[i]) * 16777619u;
    }
    return hash;
}

}  // namespace

RtcState& rtcState() { return state; }

bool rtcStateValid() {
    return state.magic == RTC_MAGIC && state.checksum == computeChecksum(state);
}

void resetRtcState() {
    memset(&state, 0, sizeof(state));
    state.magic = RTC_MAGIC;
    commitRtcState();
}

void commitRtcState() { state.checksum = computeChecksum(state); }

WakeReason wakeReason() {
    switch (esp_sleep_get_wakeup_cause()) {
        case ESP_SLEEP_WAKEUP_TIMER: return WakeReason::Timer;
        case ESP_SLEEP_WAKEUP_EXT0:
        case ESP_SLEEP_WAKEUP_EXT1: return WakeReason::Motion;
        default: return WakeReason::ColdBoot;
    }
}

[[noreturn]] void sleepUntilNextEvent(uint32_t seconds) {
    commitRtcState();

    /*
     * POWER: disconnect(true, true) drops the AP and wipes stored config, then
     * the radio is stopped and deinited. Calling only WiFi.disconnect() leaves
     * the PHY powered — about 1 mA that follows you into deep sleep and is
     * invisible without a meter on the rail.
     */
    WiFi.disconnect(true, true);
    WiFi.mode(WIFI_OFF);
    esp_wifi_stop();
    esp_wifi_deinit();

    /*
     * Measured, not guessed: with the teardown above in place a shake never
     * woke the device, and with it skipped the wake counter climbed on every
     * shake. Stopping and deinitialising the radio releases its power
     * management locks, which leaves the RTC peripheral domain configured off,
     * and ext0 runs on that domain. Assert it back on before arming.
     */
    esp_sleep_pd_config(ESP_PD_DOMAIN_RTC_PERIPH, ESP_PD_OPTION_ON);

    /*
     * POWER: the board's VCC is on the 3V3 rail -- PIN_EPD_PWR drives a switch
     * on the board, not its supply -- so it is powered even while we sleep, and
     * a data pin held at 0 V against its input pull-up sinks current forever.
     * High-impedance costs nothing and is safe here only because the board has
     * its own supply; floating into an unpowered board would feed it through
     * its ESD diodes instead.
     *
     * PIN_EPD_PWR is the exception, because it is an enable rather than a
     * signal: high turns the board's power circuit on, and an enable left
     * floating sits wherever the board's own pull takes it. Driven low and
     * held, so the circuit is off however the board pulls.
     *
     * PIN_STATUS_LED is likewise driven: it is the XIAO's own LED, active low,
     * and a floating pad lights it.
     */
    for (int pin : EPD_PINS) {
        gpio_hold_dis(static_cast<gpio_num_t>(pin));
        if (pin == PIN_EPD_PWR) {
            continue;
        }
        pinMode(pin, INPUT);
    }
    for (int pin : {PIN_EPD_PWR, PIN_STATUS_LED}) {
        pinMode(pin, OUTPUT);
        digitalWrite(pin, pin == PIN_STATUS_LED ? HIGH : LOW);
        gpio_hold_en(static_cast<gpio_num_t>(pin));
    }
    gpio_deep_sleep_hold_en();

    /*
     * POWER: every unused pin gets an explicit pull. A floating CMOS input
     * oscillates around its threshold and burns current that is very hard to
     * attribute later.
     */
    for (int pin : UNUSED_PINS) {
        pinMode(pin, INPUT_PULLDOWN);
    }

    /*
     * INT1 is push-pull active-high, so ext0 waits for a 1 and needs no
     * internal pull. armForSleep must already have settled the line.
     *
     * No rtc_gpio_* setup here: touching the pad outside of
     * esp_sleep_enable_ext0_wakeup's own configuration stopped the wake
     * firing at all.
     */
    esp_sleep_enable_ext0_wakeup(static_cast<gpio_num_t>(PIN_ACCEL_INT1), 1);

    esp_sleep_enable_timer_wakeup(static_cast<uint64_t>(seconds) * 1000000ULL);

    /*
     * POWER: the RTC peripheral domain stays on, and that is deliberate. ext0
     * runs on it, so powering it down to save tens of µA silently disables the
     * motion wake — the device sleeps, wakes on the hourly timer, and ignores
     * every shake, with nothing in any log to say why. Measured on hardware:
     * with the domain powered down a shake never wakes it; with it on, it
     * wakes every time. Do not add esp_sleep_pd_config here without measuring
     * the sleep current first and re-testing a shake after.
     */

    Serial.flush();
    esp_deep_sleep_start();

    // esp_deep_sleep_start does not return.
    for (;;) {
    }
}

}  // namespace polaroid

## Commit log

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2026-08-12 Target the XIAO ESP32S3; correct the battery to Adafruit #2011
    The XIAO ships in two days direct from Seeed, which makes it the board to
    build around rather than a nice-to-have. It costs 53 photos against the 123 a
    16MB SuperMini would give, and buys back onboard LiPo charging (deletes the
    TP4056 from a footprint with no room to spare) and the absence of an always-on
    power LED - which on the generic SuperMini is 1-3mA, fifty times the rest of
    the sleep budget, and has to be physically cut off.
    The battery link was wrong: B0FT3CZ6N1 is a 102050 1000mAh cell, not the
    103450 2000mAh the search claimed. Switched to Adafruit #2011, which is also
    better for the layout - 60x36x7mm is 39% of the pa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
2026-08-12 Add the enclosure, and an out-of-power screen the couple can actually read
    Two changes that both come down to the device explaining itself.
    BATTERY INDICATORS
    Low battery already composited a corner icon onto a refresh that was happening
    anyway. Critical battery just went to sleep silently, which on e-ink means the
    photo freezes and never changes again - indistinguishable from "the gift
    broke".
    Now, at 5%, the device draws a full-screen card once and stops: an empty
    battery glyph in the square image area and CHARGE ME on the chin, laid out to
    match the Polaroid frame the photos use, so it reads as a Polaroid somebody
    wrote on rather than as an error screen. E-ink holds it with no power at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
    [front_bezel.stl, polaroid_enclosure.scad, rear_tray.stl]
2026-08-12 Document the S3-only store and the polaroid subdomain
    The manifest hash is now the framebuffer object's S3 ETag rather than a
    SHA-256 prefix computed at upload time. It is content-derived by S3 from the
    bytes it will actually serve, so unlike a stored digest it cannot drift from
    the object it describes.
2026-08-12 Accept HEIC uploads
    Only the iOS photo-library picker transcodes HEIC to JPEG. The Files picker,
    macOS drag-drop, and anything AirDropped all deliver the real thing, and the
    people uploading here shoot on iPhones - so this is a normal path, not an edge
    case, and the failure would land the moment someone is trying to add a photo.
    Decoded with heic-decode, which is emscripten-built JS rather than a native
    binding: it bundles standalone under esbuild, verified, unlike sharp. Costs
    1.5MB against a bundle the AWS SDK already puts at 31MB.
    Fixture is a real HEIC generated with sips, so the test exercises libheif
    rather than a renamed JPEG.
2026-08-13 Preview URLs are presigned S3, and the page stays on the apex
    previewUrl pointed at /polaroid/preview/{id}.png, which was never a route -
    the manage page's thumbnails would have 404'd. Presigning is the better fix
    than adding one: an <img src> has to be a plain GET, so it could not have used
    the POST-with-body shape the other id-bearing routes use, and routing
    thumbnails through API Gateway would base64-inflate each one through a Lambda
    while the bucket stays private either way.
    Also drops the polaroid.maxrosoff.com subdomain: the page lives at
    /polaroid on the apex, so no extra CORS origin and no extra WebAuthn
    expectedOrigin.
    [main.cpp]
2026-08-13 Drop the render CLI from the docs; correct test counts
    The API returns the same bytes to a curl with the device token, so a local
    renderer was a second way to do one thing.
2026-08-13 One request per photo instead of ranged chunks
    The chunking was justified as keeping a framebuffer out of the device's RAM.
    It doesn't: HTTPClient::writeToStream already streams the body to the file in
    ~1.4KB reads, so a single request never buffers 120KB either. Resumption
    wasn't real either - a failed chunk broke the loop and the partial file was
    deleted.
    What it did buy was a TLS handshake per chunk, since http.end() closes the
    connection each iteration: 15 per photo, ~800 on a 53-photo first sync, at one
    to two seconds of CPU each. Removing it takes that to one handshake per photo.
    Server-side Range support goes too, along with parseRange - nothing sends the
    header now.
    [Config.h]
2026-08-13 Cap photos at 50
    The 8MB LittleFS fits 53 framebuffers, but downloadPhoto stages a full
    120,000-byte temp file before renaming it over the old one. At 53 there are
    62,528 bytes free - half a frame - so a full device could never replace a
    photo. Three spare frames is what makes replacement work.
    MAX_PHOTOS was 64 here, above even the physical limit, so a device handed a
    large manifest would have thrashed downloads that could not fit. The service
    caps the manifest to the newest 50 as well, so the radio is never spent on
    photos with nowhere to go.
    A native test asserts the headroom, so the limit cannot creep back up to the
    number that merely fits.
    [Config.h]
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2026-08-13 Back off failed syncs, show an offline icon, fold manifest into /photo
    secondsSinceSync was only reset on success, so a failed sync retried on the
    next hourly wake and every hour after. Through a router outage that is 24
    connect timeouts a day - 15s at 120mA each, ~12 mAh - against a total daily
    budget of 11 mAh. It would have halved runtime with no visible symptom.
    Failures now count into RTC state and drive syncInterval(): 1h, 2h, 4h up to
    the normal daily cadence, measured from the last attempt. A shake still forces
    an immediate sync, so there is always a manual retry.
    After three consecutive failures the panel draws a small offline icon - signal
    bars with a slash - in the chin beside t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
    [Config.h, main.cpp]
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2026-08-13 Photos fill the panel; no drawn Polaroid frame
    The pipeline was cropping to a 356px square and painting a white border and a
    deep chin around it, imitating a print. That spent a third of the panel on
    white and threw away a third of every photo. Photos now render full-bleed
    across all 400x600.
    Removes the frame geometry and the fullBleed option that selected between the
    two. The enclosure's argument for having no physical chin no longer rests on
    there being a drawn one, so that comment is corrected too, as are the overlay
    comments that placed the battery and offline icons 'in the chin'.
    [polaroid_enclosure.scad]
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2026-08-21 Motion means sync; drop fridge mode
    Shake syncs, the timer rotates. There is no second gesture to tell apart, so
    the click detector and everything that fed it goes: CLICK_THRESHOLD and its
    three timing constants, CLICK_REQUIRE_DOUBLE, FRIDGE_MODE_ENABLED,
    MotionEvent::Fridge, Mode::Fridge, and the CLICK_SRC-before-INT1_SRC ordering
    that only mattered when both detectors were live.
    Two bugs found on the bench, either of which alone would have sunk this.
    CTRL2 was 0x0C, which enables the high-pass filter for the click detector and
    the output registers but not for the activity generator — bit 0, HP_IA1, was
    clear. Unfiltered, gravity is 1 g against a 0.75 g threshold, so INT1 sat
    asserted f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
    [Config.h, Motion.cpp, main.cpp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]
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2026-08-21 Make the device actually fetch and show a photo
    Four bugs, all of which needed real hardware to find, and any one of which
    was enough to leave the panel blank.
    LittleFS never mounted. The partition is labelled "littlefs" in every
    partitions_*.csv, and LittleFS.begin() looks partitions up by label with
    "spiffs" as its default. storage.begin() therefore failed on every boot and
    setup() took its early bail, so the firmware never reached WiFi, sync or the
    panel. Naming the partition explicitly fixes it. Virgin flash then mounts as
    corrupt rather than blank, which format-on-fail does not cover, so a failed
    mount now formats once and retries.
    A cold boot zeroes secondsSinceSync, so the interval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
    [Config.h, Motion.cpp]
2026-08-21 Stat the framebuffer after closing it, not before
    writeToStream wrote all 120,000 bytes and the download was then thrown away
    as incomplete: File::size() on a handle still open for writing reports the
    size the file had when it was opened, which is zero. Every good download
    failed this check, which from the outside was indistinguishable from a
    network fault.
    Also logs the HTTP status, content-length and bytes written, which is what
    made the difference visible: "wrote 120000" directly above "short file: 0
    bytes" is the whole diagnosis.
    The dev build no longer deep sleeps either. Sleep drops USB, taking the
    serial log and the ability to flash without holding BOOT through a reset;
    staying awak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
    [Config.h, main.cpp]
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2026-08-22 Put the RTC peripheral domain back after tearing down WiFi
    Shake-to-wake never fired on the real firmware, while a minimal program that
    armed ext0 and slept woke every time. The difference was the radio: stopping
    and deinitialising WiFi releases its power management locks and leaves
    ESP_PD_DOMAIN_RTC_PERIPH configured off, and ext0 runs on that domain.
    Asserting it back on before arming fixes it, so the radio still gets torn
    down properly and the PHY's milliamp does not follow us into deep sleep.
    Measured rather than reasoned about, after four wrong guesses. A build that
    skipped the WiFi teardown counted nine motion wakes across two shakes; the
    same build with the teardown counted zero acro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
    [Motion.cpp, State.cpp, main.cpp]
2026-08-22 Measure the driver board instead of assuming it
    board_t was an assumed 6.0 and the real board is 7.0, so the case would have
    come up a millimetre short of closing on the first print. The comment that
    flagged it as the number most likely to be wrong was right.
    batt_puff_clearance goes 1.5 to 2.0 to match Forager, which uses the same
    2000 mAh cell and got its allowance off a real print rather than a guess.
    Case is 22.95mm rather than 21.45mm. Still unresolved: the assembled stack
    measures about 25mm with wiring, which the depth calculation does not budget
    for at all, since it sums glass, board and battery and assumes the harness
    takes no vertical space.
    [front_bezel.stl, polaroid_enclosure.scad, rear_tray.stl]
2026-08-22 Give the case a chin, and size its depth from the real assembly
    The parts do not fit under the board. Battery, MCU, accelerometer and the
    harness all share one layer beneath a driver board that spans the whole
    pocket, and they ran out of floor. A 10mm chin below the pocket buys that
    floor back, and it is what an instant print looks like anyway, so the header's
    old objection to a chin no longer applies: this one is driven by fit, not by
    styling.
    Depth now follows a measured stack of 28mm rather than the parts-list sum,
    which came to 17mm because wires are not in the parts list. They cross the
    battery, stand off solder joints, and hold whatever curve they were bent
    into. The sum stays as a fl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
    [front_bezel.stl, polaroid_enclosure.scad, rear_tray.stl]
2026-08-23 Enclosure v2, fitted against the first print
    Everything here came off measuring the printed parts, except the interference,
    which came off intersecting them.
    THE BOW. The bezel bowed along both long sides once screwed down, and it was
    not the print. Intersecting the two assembled solids found four overlaps: each
    screw flange's square outboard corner sat 0.67mm inside the tray's rounded
    interior corner, down all 12mm of flange. Four corners held proud, the screws
    pulled the ends down anyway, and the plate arced. The bezel now cuts everything
    it hangs into the cavity against the tray's own profile shrunk by the fit
    clearance, so flanges and locator bars cannot collide with the tray by
    constru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
    [fit_check.scad, front_bezel.stl, polaroid_enclosure.scad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]
2026-08-25 Enclosure v3, millimetre pinching against the second print
    SIZE, 71.6 x 130.6 x 26.8 to 71.6 x 118.8 x 22.7. Nothing here is a new
    feature; it is four places the case was paying for something it did not use.
    WINDOW. v2 measured the image landing 1.8mm off and turned active_offset_y to
    -1.8, which is the wrong sign: negative moves the window down and down was
    already the error, so the second print is out by 3.5 rather than 2. The knob
    goes to +1.7, which is that -1.8 backed out plus the 1.7 still measured short.
    The comment now says which way the sign runs, since that is the thing the last
    edit got wrong.
    FLOOR, 5.6 to 1.5mm. The floor was thick enough everywhere to swallow the
    magnet pocke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
    [fit_check.scad, front_bezel.stl, polaroid_enclosure.scad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]
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2026-08-26 Wake on a shake again: clock the debounce from the RTC, not esp_timer
    Shake to sync had not worked since the device was assembled. The accelerometer
    was fine, ext0 was fine, and the gesture still did nothing.
    motionTooSoon() compared esp_timer_get_time() against a value kept in RTC
    memory. esp_timer is microseconds since esp_timer_init(), which runs early in
    application startup -- and a deep-sleep wake IS an application startup, so it
    restarts near zero every wake. lastMotionMillisSinceBoot starts at zero too, so
    the very first motion wake computed roughly 150 - 0 = 150 < 3000 and returned
    "too soon". Every shake woke the device, exited at EXIT_MOTION_TOO_SOON, and
    slept again a few hundred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
    [Config.h, Motion.cpp, Panel.cpp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]
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2026-08-26 Review fixes: stop the sync deadline deleting photos it did not fetch
    Four fixes, two of them real bugs and one of them mine from the commit before.
    SYNC DEADLINE, data loss. Net::sync walks remote.photos, pushing each entry
    into `committed`, and breaks out when SYNC_TIMEOUT_MS expires. `committed` is
    then what removeOrphans sweeps against, so anything the loop never reached is
    deleted off flash.
    That was safe while the manifest was oldest-first: the entries needing a fetch
    sat at the END, so a break only abandoned photos that were not on disk anyway.
    Making it newest-first put the fetches at the FRONT and inverted the meaning of
    the break -- everything abandoned is now a photo that is alr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
    [Motion.cpp, Panel.cpp, State.cpp]
2026-08-26 Say "ADD PHOTOS" when the library is empty, and track what the panel shows
    An empty library left whatever was drawn last sitting on the panel forever.
    renderCurrentPhoto() returned before touching the hardware, so deleting every
    photo and shaking produced no visible change at all -- and a brand-new device
    that had never synced looked identical to a broken one. E-ink holding its last
    image is the whole reason the battery card exists; the same argument applies
    here.
    The card is Material Icons photo_library over "ADD PHOTOS", same machinery and
    same Jost as CHARGE ME. tools/gencard.py takes a table of cards now, so a third
    is one line. add_a_photo was the obvious icon and is not usable: its "+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
    [main.cpp]
2026-08-26 Blank until the first photo, and an empty library that is not an error
    TWO SCREENS, NOT ONE. An empty library meant one thing before: show the card.
    It means two, and they want different answers.
    never held a photo -> solid white, nothing else
    held one, now empty -> ADD PHOTOS
    A new frame is a gift, and the first thing anyone sees should be clean paper
    rather than an instruction. Once it has held a photo, empty means someone
    deleted them, and that is worth saying.
    Telling those apart needs state that outlives the battery. A manifest file
    cannot do it: a successful sync against an empty server writes an empty one, so
    a brand-new device would have shown ADD PHOTOS on day one. RTC mem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
    [Config.h, main.cpp]
2026-08-27 Hold the gate and the LED through deep sleep, and calibrate the divider
    THREE THINGS, all found chasing a battery that ran flat in days against a
    budget predicting months.
    GPIO STATE IS NOT RETAINED THROUGH DEEP SLEEP unless it is held, and nothing
    here held anything. Two pads could not be allowed to float and both were:
    - PIN_EPD_PWR gates the panel driver board's rail. Panel::powerDown drives it
    low, and the instant esp_deep_sleep_start ran it stopped being driven --
    so the gate floated for the entire sleep and the rail could sit powered.
    That is the one thing this pin exists to prevent.
    - PIN_STATUS_LED is GPIO21, the XIAO's own user LED, ACTIVE LOW. It appeared
    in n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
    [Config.h, State.cpp, main.cpp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]
2026-08-30 Hold every panel pin through deep sleep, not just the gate
    This is the drain. The first assembled build ran flat in days against a budget
    predicting five months, and it was never the refresh.
    Cutting PIN_EPD_PWR does not turn the panel off. A GPIO stops being driven the
    moment the chip deep sleeps unless explicitly held, so the six data and control
    lines float the instant we sleep -- and a floating pin sitting at a driver
    board's input forward-biases that board's ESD diodes and feeds its rail through
    the input pin. The panel gets powered through the back door the gate was closed
    to prevent.
    MEASURED, three runs of ~18 h each from the same 4.22 V start:
    never touches the panel 4.2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
    [Config.h, State.cpp, main.cpp]
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2026-08-30 Drop the low-battery corner icon
    Not wanted on the photo. It was a 24x12 red battery composited into the
    bottom-right corner of every refresh below 15%, and it has been there since the
    first firmware commit.
    The offline icon stays: it is a different signal, and nothing asked for it to
    go. Its compositor loses the comment about not overlapping the battery box,
    since there is no longer a box to overlap, and the assertion that checked it
    goes with the tests that exercised the battery icon.
    battery.low and LOW_BATTERY_PERCENT stay. They are no longer drawn but the
    per-wake log line still reports "low", which is worth having while reading a
    discharge run, and the threshold is what defines it. N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
    [main.cpp]
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2026-08-30 Remove LOW_BATTERY_PERCENT and the "low" flag with it
    The threshold existed to drive the corner icon, and 535217f removed the icon.
    What was left drew nothing and only tagged a log line, which is not worth a
    constant, a struct field, and three tests.
    Gone: LOW_BATTERY_PERCENT, BatteryReading::low, the " low" branch in the
    per-wake log, and test_low_warning_comes_before_critical, which asserted a
    relationship between two thresholds when only one of them still exists.
    test_battery_low_threshold_fires_before_empty was written against the removed
    constant but was really testing the curve, so it is replaced by
    test_battery_curve_hits_its_knots, which pins all four knots directly. That is
    a bett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
    [Config.h, main.cpp, test_config.cpp]
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2026-09-01 Log an hourly battery sample to flash
    The frame can now measure its own discharge. Every wake appends
    boot, rtc time, millivolts, wake reason and whether USB was attached;
    plugging in dumps the log and 'c' clears it.
    Reading the cell over the cable measures the charger instead. Three
    samples eleven seconds apart read 4229, 4147 and 4143 mV, and the low one
    was the only one taken with the cable out -- an 86 mV spread against 4.8
    mV of ADC noise. Sampling on battery and reading back later is the only
    way to get a number that means anything.
    It goes in powerDownAndSleep because every exit from setup() comes
    through there, so a wake is sampled exactly once however it ends.
    Bounded by rotation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
    [Config.h, main.cpp]
2026-09-02 Skip a panel refresh that would redraw the same image
    With one photo in the library the index stays at zero, so every timer
    wake repainted the identical picture: 24 full 21-second refreshes a day,
    flashing the panel for nothing. The empty-library branch already guarded
    against this; the photo path did not.
    Keyed on the photo's hash rather than its index. The photo at a given
    index changes under you when a sync adds or drops one, and two different
    pictures share an index. The offline icon is mixed in because it is part
    of what gets drawn -- going offline has to repaint or the icon never
    appears.
    Worth about 6 mAh/day of the measured 122, so it does not move the
    battery today. It matters if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
    [main.cpp]
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2026-09-02 Leave the panel pins high-impedance in deep sleep
    The board's VCC is wired to the 3V3 rail, not through PIN_EPD_PWR -- that
    pin drives a switch on the board, not its supply. So the driver board is
    powered continuously, and the pins reaching it are inputs on a live
    device.
    That makes driving them low backwards. A powered board pulls its inputs
    up to its own VCC, and a pin held at 0 V against a pull-up sinks current
    forever: 3V3, through the resistor, through our pad, to ground. Six lines
    through 4.7k is about 4 mA -- the size of the drain we cannot account
    for.
    The reasoning being replaced describes an unpowered board, where floating
    inputs forward-bias its ESD diodes and feed its rail back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
    [State.cpp]
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2026-09-10 Drive the panel enable low in sleep, not high-impedance
    PIN_EPD_PWR is an enable, not a signal: Panel::begin drives it high to
    turn the board's power circuit on. It was a member of EPD_PINS, so the
    high-impedance change left it floating in deep sleep -- and an enable
    line left floating sits wherever the board's own pull takes it, which for
    a default-on design means the board has been fully enabled every night
    since that flash.
    That fits the numbers. Leaving the six data lines high-Z recovered 1.9 mA
    but stalled around 2-3 mA rather than falling to microamps, which is what
    a board that is idle-but-enabled would look like.
    So the data and control lines stay high-Z, and the enable is driven l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
    [State.cpp]
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2026-09-13 Make the logs readable
    Every line is now `[uptime elapsed] tag | message` in a fixed-width
    column, so a capture scans down it and a subsystem can be grepped without
    matching prose. Lines were previously a mix of bare sentences,
    "category: detail", and sub-lines hand-indented two spaces.
    Two clocks, because the questions differ. Uptime comes from the RTC and
    counts through deep sleep, so it places a wake among all the others;
    seconds-since-boot restart each wake and show how long a step took -- the
    panel refresh is now a visible 21-second jump rather than something to
    infer from the host's own clock.
    No line prints a bare enum: "exit=1" is "exit normal". Net's indent
    becomes the tag it was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
    [main.cpp]
2026-09-13 Print the device id at boot, and ignore per-device secrets
    A build carries exactly one device id, baked in from Secrets.h, and
    nothing else on the device said which. Flashing the wrong frame's build
    is otherwise silent: it authenticates, syncs someone else's photos, and
    looks entirely healthy. That happened, and took a second pair of eyes to
    notice rather than anything in a log.
    The gitignore only covered `secrets.h` in lowercase and worked by
    accident on a case-insensitive filesystem, so the per-device files
    (Secrets.max.h, Secrets.matt.h) would have been committed. Both Secrets.h
    and Secrets.*.h are now ignored.
    [main.cpp]
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2026-09-13 Flatten the firmware into the repo root
    One board and one build, so the extra directory level only bought a cd. Merges the two gitignores and fixes the paths that named it.
    [partitions.csv, polaroid_enclosure.scad]
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
